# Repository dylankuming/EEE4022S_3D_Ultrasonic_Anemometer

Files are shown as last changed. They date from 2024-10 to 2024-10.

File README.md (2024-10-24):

# EEE4022S 3D Ultrasonic Anemometer

This repository contains the complete development files for the **3D Ultrasonic Anemometer** project developed as part of the EEE4022S course. The goal of the project is to design, build, and test a low-cost, accurate, and reliable 3D ultrasonic anemometer using Commercial-Off-The-Shelf (COTS) components. The system measures wind data in three dimensions (X, Y, and Z) using ultrasonic transducers and provides real-time data visualisation.

## Repository Structure

This repository is organized into three main directories:

1. **Arduino_code**: Contains all the Arduino code required to interface with the ultrasonic transducers, perform wind speed and direction calculations, and handle the data acquisition process.
   - [More details can be found in the `Arduino_code/README.md`](https://github.com/dylankuming/EEE4022S_3D_Ultrasonic_Anemometer/blob/main/Arduino_code/README.md)

2. **KiCad_folders**: Includes the KiCad schematics and PCB design files for the digital and analog circuits used in the project. These files outline the hardware design and connections between components. The following KiCad folders are included:

   - **Analog Board**: Contains the PCB design for the analog circuit.
     - [More details can be found in the `Analog Board README.md`](https://github.com/dylankuming/EEE4022S_3D_Ultrasonic_Anemometer/blob/main/KiCad_folders/analog_board/README.md)

   - **2D Digital Board**: Contains the PCB design for the 2D digital circuit.
     - [More details can be found in the `2D Digital Board README.md`](https://github.com/dylankuming/EEE4022S_3D_Ultrasonic_Anemometer/tree/main/KiCad_folders/2d_digital_board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)

   - **3D Digital Board**: Contains the PCB design for the 3D digital circuit.
     - [More details can be found in the `3D Digital Board README.md`](https://github.com/dylankuming/EEE4022S_3D_Ultrasonic_Anemometer/blob/main/KiCad_folders/3d_digital_board/README.md)

3. **matlab_code**: This directory contains MATLAB scripts used for data visualization and further analysis of the anemometer's outputs. The scripts allow for the real-time display of wind speed and direction data.
   - [More details can be found in the `matlab_code/README.md`](https://github.com/dylankuming/EEE4022S_3D_Ultrasonic_Anemometer/blob/main/matlab_code/README.md)

## Getting Started

### Prerequisites

- Arduino IDE for uploading and running the Arduino code.
- KiCad for viewing and editing the PCB design files.
- MATLAB for running the data visualization scripts.

### Installation and Usage

1. **Arduino Code**: Navigate to the `Arduino_code` folder, open the relevant `.ino` file in the Arduino IDE, and upload it to your Arduino board.
2. **KiCad Files**: Open the KiCad project files in the `KiCad_folders` directory to explore or modify the circuit designs.
3. **MATLAB Scripts**: Run the MATLAB scripts from the `matlab_code` folder to visualize the wind data captured by the anemometer.

## License

This project is open-source, and all contributions are welcome. You are free to modify and distribute the code under the terms of the MIT license.

## Author

- **Dylan Kuming**
  - Date: October, 2024

## Acknowledgements

This project was supervised by **Dr. Stephen Paine** and completed as part of the EEE4022S course at the **University of Cape Town**.

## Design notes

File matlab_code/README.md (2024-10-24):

# MATLAB Wind Visualisation for 3D Ultrasonic Anemometer

This MATLAB script connects to an Arduino via serial communication and streams wind speed data from the **3D Ultrasonic Anemometer** in three axes: North-South (NS), East-West (EW), and Top-Bottom (TB). The script processes this data and visualizes it in real time using multiple plot types, including 3D quiver plots, line graphs, and polar plots.

## Features

- **3D Quiver Plot with Trailing Vectors**: Shows the wind direction and magnitude in real time in a 3D space, along with trailing lines for visual tracking.
- **Smoothed Line Graph**: Displays the wind speed over time for all three axes (NS, EW, TB).
- **Polar Plot**: Illustrates the resultant wind direction and speed on a polar graph.
- **Digital Readout**: Provides real-time information on the resultant wind speed, direction (in both degrees and cardinal direction), and elevation angle.
  
## How to Use

### 1. Connect the Arduino

- Make sure the Arduino, loaded with [`3D_Ultrasonic_Anemometer.ino`](https://github.com/dylankuming/EEE4022S_3D_Ultrasonic_Anemometer/blob/main/Arduino_code/3D_Ultrasonic_Anemometer.ino), is connected to your computer and is streaming wind data via a serial connection.
- Replace `"COM3"` in the script with the correct port for your Arduino (you can find the correct port in the Arduino IDE).

```matlab
s = serialport("COM3", 9600); % Change "COM3" to your Arduino's COM port
```

### 2. Run the Script

- Open the [3D_Matlab_visual_output.m](https://github.com/dylankuming/EEE4022S_3D_Ultrasonic_Anemometer/blob/main/matlab_code/3D_Matlab_visual_output.m) script in MATLAB.
- Run the script by pressing the **Run** button or by typing `run` in the MATLAB command window.

### 3. Visualisation

- The script collects 1000 data points from the Arduino and updates the following visualisations in real time:
  - **3D Quiver Plot**: A 3D vector plot that shows wind direction and magnitude in space, with a trailing line for visual history.
  - **Line Graph**: A real-time plot of wind speed over time for each axis (NS, EW, TB).
  - **Polar Plot**: Displays the resultant wind direction and speed on a polar coordinate plot.
  - **Digital Readout**: Displays current wind speed, direction (in degrees and cardinal direction), and elevation angle.

### 4. Data Collection and Visualisation

- The script collects data for 1000 iterations, where each data point contains the wind speed along the NS, EW, and TB axes. 
- It calculates:
  - **Resultant Wind Speed**: The overall wind speed from the three components.
  - **Wind Direction**: The direction of the wind in degrees.
  - **Cardinal Direction**: The wind direction in cardinal terms (e.g., North, East, South, etc.).
  - **Elevation Angle**: The vertical component of the wind based on the TB axis.
  
### Sample Data Format (from Arduino):
```plaintext
NS:<value>,EW:<value>,TB:<value>
```

### Example Output
- Wind speed: `8.65 m/s`
- Wind direction: `45.0° (North-East)`
- Elevation angle: `12.5°`

## Visualisation Details

- **3D Quiver Plot**: Visualizes wind vectors in a 3D space, showing the real-time wind direction and magnitude. The plot is updated dynamically as new data is received from the Arduino.
- **Smoothed Line Graph**: Shows the wind speed variation over time for each axis (NS, EW, TB). The plot is continuously updated as data is received.
- **Polar Plot**: Displays the resultant wind direction and speed on a polar graph, helping users visualize where the wind is coming from.
- **Digital Readout**: Provides real-time numerical values for resultant wind speed, direction, and elevation.

## License

This MATLAB script is open-source and available for modification and distribution. Feel free to use and improve upon the code.

## Author

- **Dylan Kuming**
  - Date: October, 2024

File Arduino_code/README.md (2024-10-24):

# 3D Ultrasonic Anemometer Arduino Code

This project implements a **3D ultrasonic anemometer** for measuring wind data across three axes: North-South (NS), East-West (EW), and Top-Bottom (TB). The system uses ultrasonic transducers and calculates wind speed by measuring the time-of-flight (ToF) of sound pulses between the transducers.

The original 2D version of the code was written by **Lukas Fässler** and has been modified for 3D wind measurements by **Dylan Kuming**.

## Overview

The **3D Ultrasonic Anemometer** measures wind speed in all three dimensions using ultrasonic transducers. The time difference in sound pulses between pairs of transducers provides the wind speed, while the direction and elevation angle are computed based on phase and vertical components.

### Key Features:
- **3D Wind Measurement**: Accurate wind measurement in NS, EW, and TB axes.
- **Temperature Sensor**: Used for temperature compensation as it affects the speed of sound.
- **LCD Display**: Provides a real-time display of measurements.
- **Arduino Controlled**: The system is managed using an Arduino microcontroller.

### Components:
- **Ultrasonic Transducers**: Measure wind speed through sound waves.
- **Temperature Sensor**: Reads ambient temperature to account for speed of sound variation.
- **LCD Display**: Shows real-time measurements such as wind speed, phase, and elevation. Alternatively, for visual output, you can use the [MATLAB script](https://github.com/dylankuming/EEE4022S_3D_Ultrasonic_Anemometer/blob/main/matlab_code/3D_Matlab_visual_output.m) to generate a graphical representation.
- **Arduino**: Controls the ultrasonic pulses and processes the wind data.

### Project Structure:
- [`3D_Ultrasonic_Anemometer.ino`](https://github.com/dylankuming/EEE4022S_3D_Ultrasonic_Anemometer/blob/main/Arduino_code/3D_Ultrasonic_Anemometer.ino): Contains the Arduino code that handles the measurement process.

## How It Works

1. **Sound Pulse Emission**: The Arduino controls the ultrasonic transducers to emit sound pulses along the three axes.
2. **Time-of-Flight (ToF) Calculation**: The time taken for the pulse to travel between transducers is measured.
3. **Wind Speed and Direction**: Wind speed is calculated from the difference in ToF along opposite directions (e.g., NS vs SN). The direction is determined using trigonometry.
4. **Vertical Wind Component**: The system also calculates the vertical wind speed using the top-bottom axis.

### Measurements:
- **NS Wind Speed**: Wind speed in the North-South axis.
- **EW Wind Speed**: Wind speed in the East-West axis.
- **TB Wind Speed**: Wind speed in the Top-Bottom axis.
- **Magnitude**: Overall wind speed magnitude across the three axes.
- **Phase**: Wind direction in degrees.
- **Elevation**: Vertical angle of the wind.

## Hardware Setup

The following components and connections are used in the project:

- **AXIS1 (Pin 13)**: Determines the operational plane for measurement.
- **AXIS2 (Pin 12)**: Controls the second axis (NS/EW vs TB).
- **DIRECTION (Pin 11)**: Sets the direction of the sound pulse.
- **SIGNAL (Pin 10)**: Pulse Width Modulation (PWM) signal for driving transducers.
- **MUTE (Pin 9)**: Mutes the amplifier during transmission and unmutes during reception.
- **Envelope Detector (Pin 7)**: Captures the envelope of the signal.
- **Zero-Crossing Detector (Pin 8)**: Captures the zero-crossing signal.
- **Temperature Sensor (Pin A0)**: Reads ambient temperature for compensating the speed of sound.
- **LCD Connections (Pins A1-A3, D3-D6)**: Used to control the 16x2 LCD.

### Additional Required Hardware:
- Ultrasonic transducers.
- [Analog Board](https://github.com/dylankuming/EEE4022S_3D_Ultrasonic_Anemometer/tree/main/KiCad_folders/analog_board).
- [3D Digital Board](https://github.com/dylankuming/EEE4022S_3D_Ultrasonic_Anemometer/tree/main/KiCad_folders/3d_digital_board).
- Arduino-compatible microcontroller.
- LCD 16x2 display.

## Output Data

The system outputs the following data over the serial interface:
- **NS Wind Speed**: Wind speed in the North-South direction (in m/s).
- **EW Wind Speed**: Wind speed in the East-West direction (in m/s).
- **TB Wind Speed**: Wind speed in the Top-Bottom direction (in m/s).
- **Magnitude**: The overall wind speed magnitude calculated using the three axes.
- **Phase**: Wind direction based on NS and EW components.
- **Elevation**: Wind elevation based on the TB axis.

The LCD displays the same data in real-time, providing an easy interface for monitoring wind conditions.

## License

This project is open-source, and all contributions are welcome. You are free to modify and distribute the code under the terms of the MIT license.

## Author

- **Dylan Kuming**
  - Date: October, 2024

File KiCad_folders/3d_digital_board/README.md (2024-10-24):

# 3D Digital Board for 3D Ultrasonic Anemometer

This folder contains the KiCad design files for the **3D Digital Board** used in the 3D Ultrasonic Anemometer. This board expands on the 2D version by adding control for the Top-Bottom (TB) axis, allowing for full 3D wind measurement. It manages the ultrasonic transducers in the NS, EW, and TB directions and processes signals for calculating wind speed and direction in three dimensions.

## Features
- **3D Wind Measurement**: Adds the third axis (Top-Bottom) to enable full 3D wind speed and direction measurement.
- **Expanded Multiplexing**: Uses additional multiplexers to handle signals from six transducers.
- **Transducer Control**: Selects and drives the appropriate transducers for the NS, EW, and TB axes.

## Key Components
- **74HC138 3-to-8 Line Decoder**: Controls the selection of transducer pairs for the three-dimensional setup.
- **74HC4051 Multiplexer**: Routes the received signals from all six transducers to the analog board for processing.
- **Hex Inverters**: Controls the ultrasonic transducers.

## Files in this Folder
- [3D_Digital_Board_Schematic.sch](https://github.com/dylankuming/EEE4022S_3D_Ultrasonic_Anemometer/blob/main/KiCad_folders/3d_digital_board/3D_Digital.kicad_sch): The KiCad schematic of the 3D digital board.
- [3D_Digital_Board_PCB.kicad_pcb](https://github.com/dylankuming/EEE4022S_3D_Ultrasonic_Anemometer/blob/main/KiCad_folders/3d_digital_board/3D_Digital.kicad_pcb): The PCB layout for the 3D digital board.

## Usage
1. **Open the Schematic**: Use KiCad to open and modify the schematic for the 3D digital board.
2. **Edit PCB Layout**: Review the PCB layout to make any necessary adjustments.
3. **Generate Gerber Files**: Export Gerber files from KiCad for PCB fabrication.

## License
This project is open-source under the MIT License.

## Author

- **Dylan Kuming**
  - Date: October, 2024

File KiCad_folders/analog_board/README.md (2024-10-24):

# Analog Board for 3D Ultrasonic Anemometer

This folder contains the KiCad design files for the **Analog Board** used in the 3D Ultrasonic Anemometer. The Analog Board plays a crucial role in processing the ultrasonic signals received from the transducers. It is responsible for signal amplification, envelope detection, and zero-crossing detection, which are required to measure the time-of-flight (ToF) of the ultrasonic pulses.

## Features
- **Signal Amplification**: Boosts the received ultrasonic signals to detectable levels.
- **Envelope Detection**: Extracts the amplitude variations of the signals for timing analysis.
- **Zero-Crossing Detection**: Detects the zero-crossing points of the ultrasonic waves for more precise ToF measurement.
- **Temperature Compensation**: Includes a temperature sensor for compensating the speed of sound based on environmental temperature.

## Components
- Tuned amplifiers for signal conditioning.
- Envelope detectors to capture signal peaks.
- Zero-crossing detectors to mark the precise timing of signal transitions.
- Temperature sensor for environmental adjustments.

## Files in this Folder
- [Analog_Board_Schematic.sch](https://github.com/dylankuming/EEE4022S_3D_Ultrasonic_Anemometer/blob/main/KiCad_folders/analog_board/Analog.kicad_sch): The KiCad schematic of the analog board.
- [Analog_Board_PCB.kicad_pcb](https://github.com/dylankuming/EEE4022S_3D_Ultrasonic_Anemometer/blob/main/KiCad_folders/analog_board/Analog.kicad_pcb): The PCB layout for the analog board.

## Usage
1. **Open the Schematic**: Load the schematic file into KiCad to view the circuit.
2. **View or Edit the PCB**: Open the PCB layout file to review the placement and routing of components.
3. **Generate Fabrication Files**: Export the necessary Gerber files from KiCad for PCB fabrication.

## License
This project is open-source under the MIT License.

## Author

- **Dylan Kuming**
  - Date: October, 2024

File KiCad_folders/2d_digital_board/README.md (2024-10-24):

# 2D Digital Board for 2D Ultrasonic Anemometer

This folder contains the KiCad design files for the **2D Digital Board** used in the 2D version of the Ultrasonic Anemometer. This board is designed to control and manage the transducers along two axes: North-South (NS) and East-West (EW). It sends and receives ultrasonic pulses and calculates wind speed and direction in two dimensions.

## Features
- **Transducer Control**: Manages the transducers for both the NS and EW axes.
- **Multiplexing**: Uses multiplexers to route the signals to and from the appropriate transducers.

## Key Components
- **74HC139 Decoder**: Controls the transducer selection for NS and EW.
- **74HC368 Hex Inverters**: Drives the ultrasonic transducers.
- **74HC4052 Multiplexers**: Routes the signals to the analog board for processing.

## Files in this Folder
- [2D_Digital_Board_Schematic.sch](https://github.com/dylankuming/EEE4022S_3D_Ultrasonic_Anemometer/blob/main/KiCad_folders/2d_digital_board/Digital.kicad_sch): The KiCad schematic of the 2D digital board.
- [2D_Digital_Board_PCB.kicad_pcb](https://github.com/dylankuming/EEE4022S_3D_Ultrasonic_Anemometer/blob/main/KiCad_folders/2d_digital_board/Digital.kicad_pcb): The PCB layout for the 2D digital board.

## Usage
1. **Open the Schematic**: Load the schematic file into KiCad to view or modify the design.
2. **View or Edit the PCB**: Review the PCB layout and adjust the component placement as needed.
3. **Fabrication**: Generate Gerber files from KiCad for PCB manufacturing.

## License
This project is open-source under the MIT License.

## Author

- **Dylan Kuming**
  - Date: October, 2024

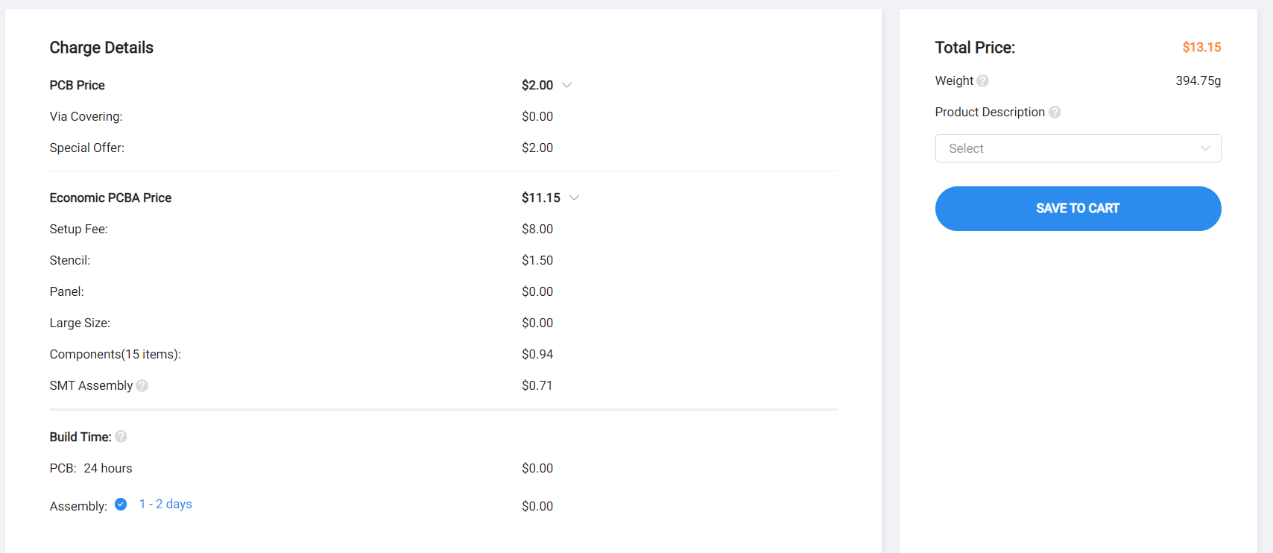
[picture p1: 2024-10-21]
KiCad_folders/analog_board/Screenshot 2024-08-29 081555.png

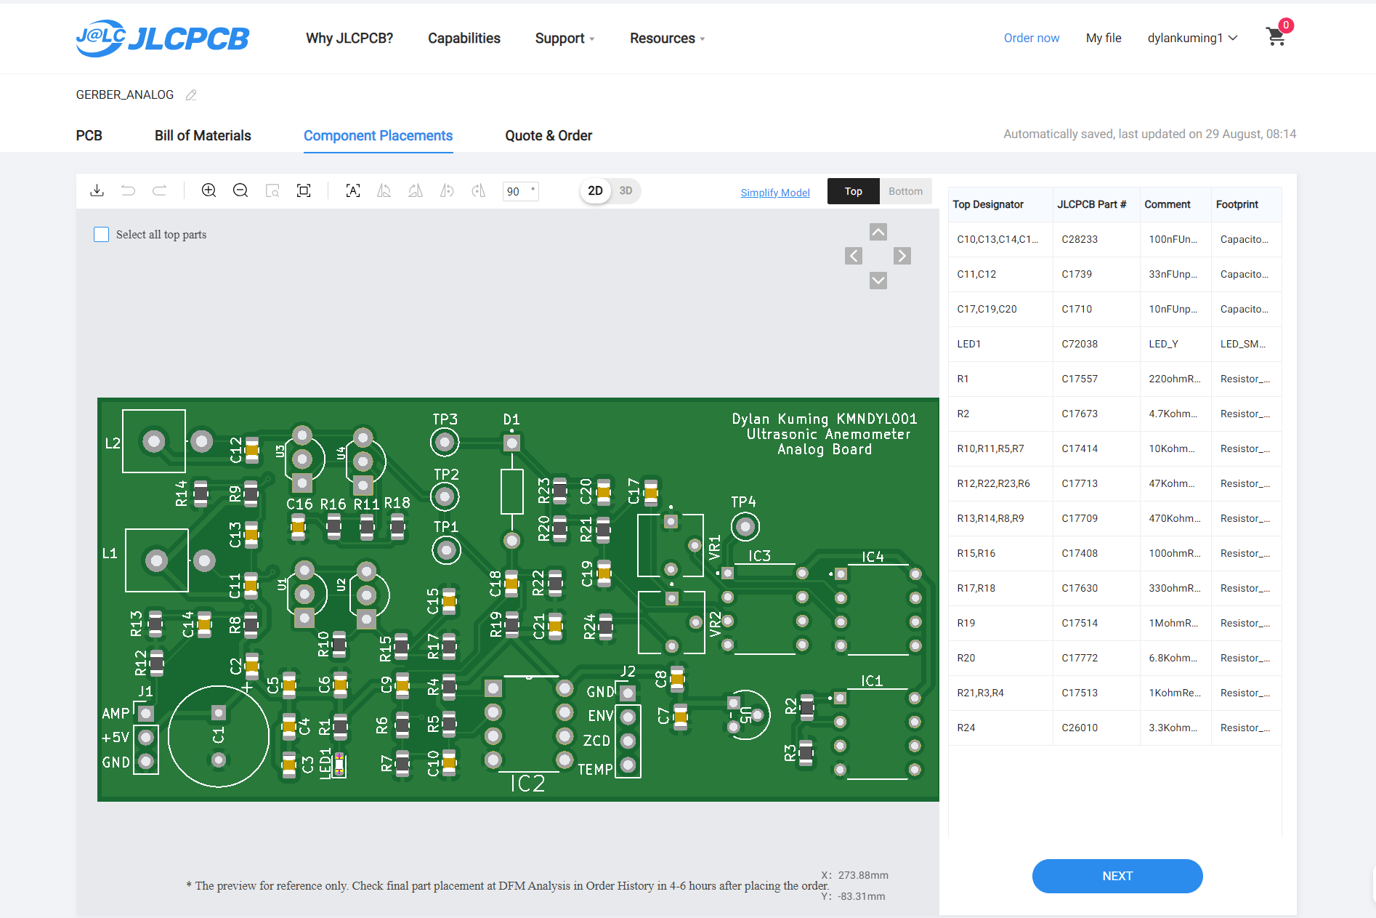
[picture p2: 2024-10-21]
KiCad_folders/analog_board/Screenshot 2024-08-29 081522.png

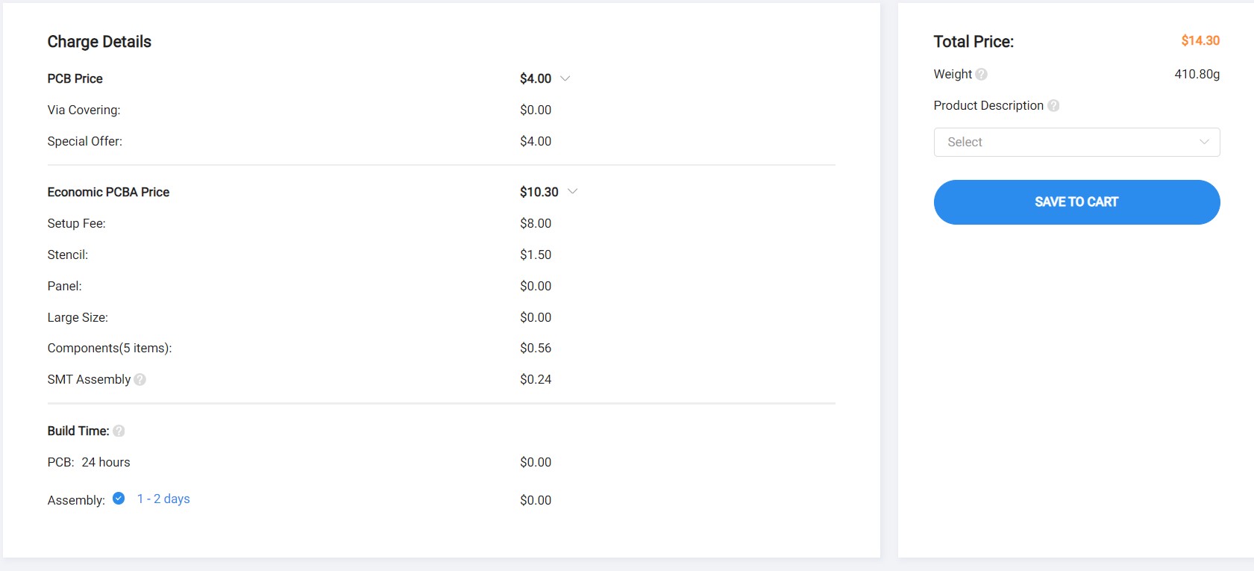
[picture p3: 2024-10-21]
KiCad_folders/3d_digital_board/Quote.jpg

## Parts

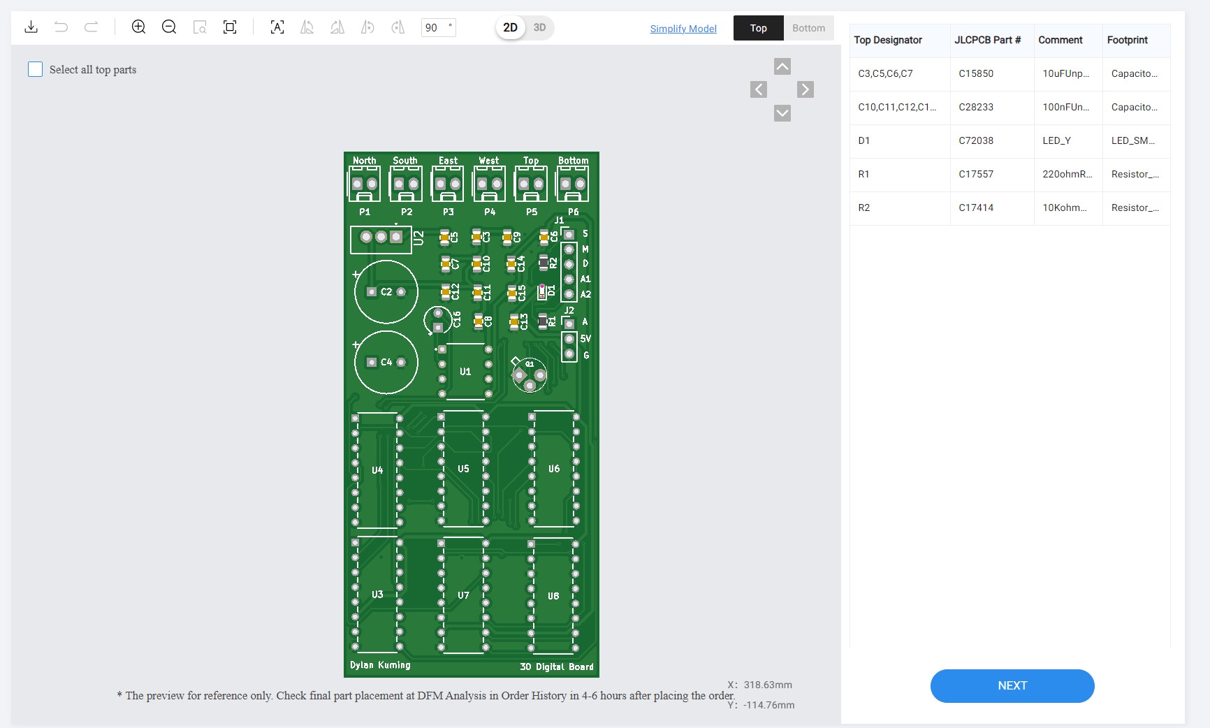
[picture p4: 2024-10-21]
KiCad_folders/3d_digital_board/Component placement.jpg

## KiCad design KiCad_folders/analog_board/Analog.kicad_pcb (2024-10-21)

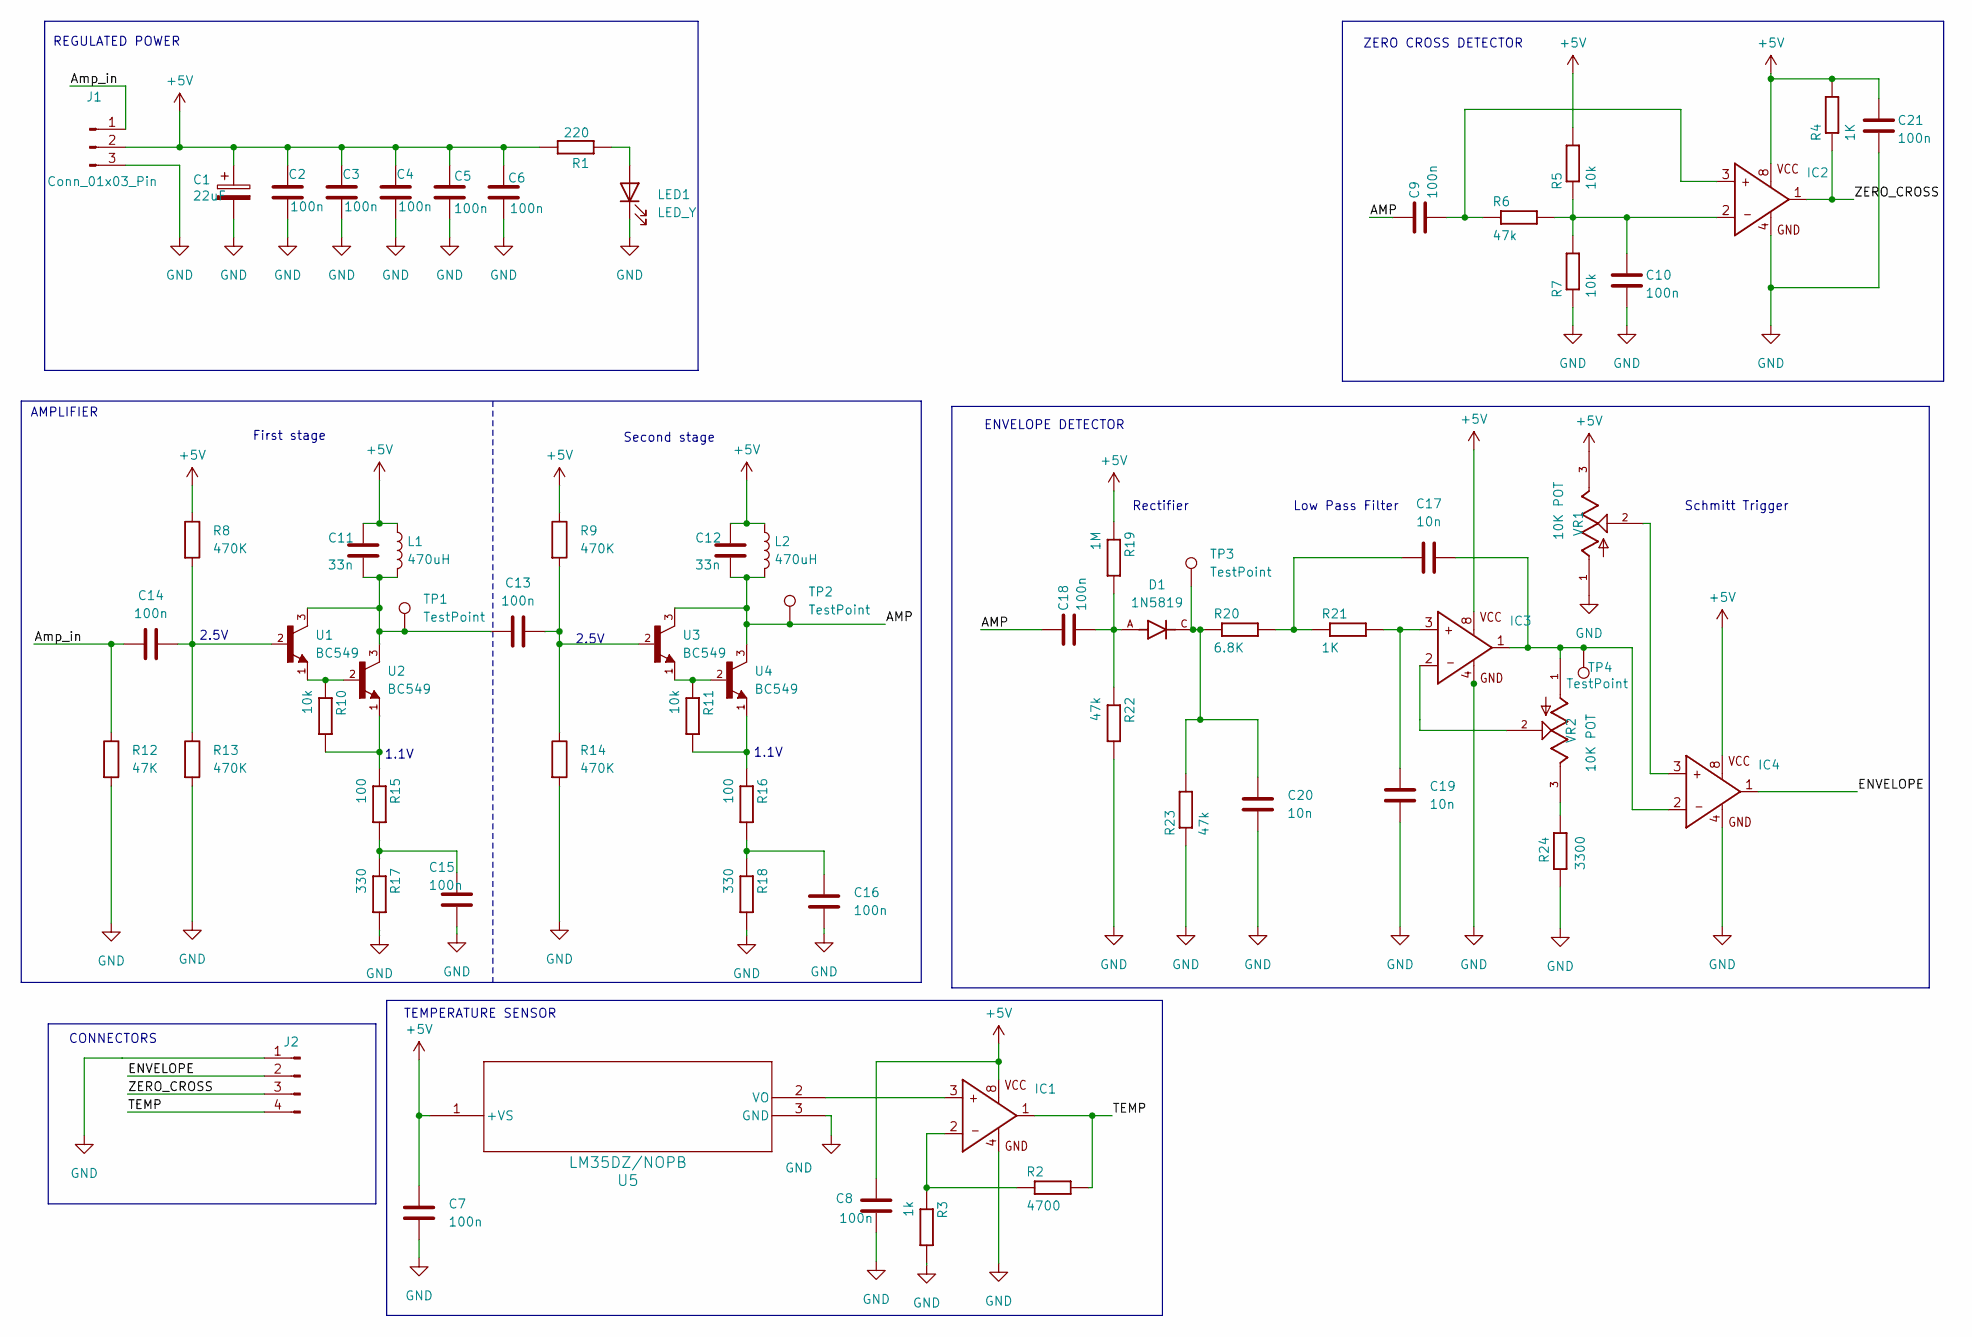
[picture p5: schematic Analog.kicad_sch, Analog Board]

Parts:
C1: 22uF; CP_Radial_Tantal_D10.5mm_P5.00mm
C2, C3, C4, C5, C6, C7, C8, C9, C10, C13, C14, C15, C16, C18, C21: 100n; C_0805_2012Metric
C11, C12: 33n; C_0805_2012Metric
C17, C19, C20: 10n; C_0805_2012Metric
D1: 1N5819; DIOAD1036W78L470D235; PARTREV P2104
IC1, IC3, IC4: LM358; DIP794W45P254L959H508Q8
IC2: LM393; DIP254P762X508-8
J1: Conn_01x03_Pin; PinHeader_1x03_P2.54mm_Vertical
J2: Conn_01x04_Pin; PinHeader_1x04_P2.54mm_Vertical
L1, L2: 470uH; R_Axial_Power_L20.0mm_W6.4mm_P5.08mm_Vertical
LED1: LED_Y; LED_0603_1608Metric
R1: 220; R_0805_2012Metric
R2: 4700; R_0805_2012Metric
R3: 1k; R_0805_2012Metric
R4, R21: 1K; R_0805_2012Metric
R5, R7, R10, R11: 10k; R_0805_2012Metric
R6, R22, R23: 47k; R_0805_2012Metric
R8, R9, R13, R14: 470K; R_0805_2012Metric
R12: 47K; R_0805_2012Metric
R15, R16: 100; R_0805_2012Metric
R17, R18: 330; R_0805_2012Metric
R19: 1M; R_0805_2012Metric
R20: 6.8K; R_0805_2012Metric
R24: 3300; R_0805_2012Metric
TP1, TP2, TP3, TP4: TestPoint; TestPoint_Loop_D2.50mm_Drill1.0mm
U1, U2, U3, U4: BC549; TO92
U5: LM35DZ/NOPB; Z03A
VR1, VR2: 10K POT; TRIM_3362P-1-503LF; PARTREV 08/26/10

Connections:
+5V: C1.1, C2.1, C3.1, C4.1, C5.1, C6.1, C7.1, C8.1, C11.1, C12.1, C21.1, IC1.8 (VCC), IC2.8 (VCC), IC3.8 (VCC), IC4.8 (VCC), J1.2, L1.1, L2.1, R1.2, R4.2, R5.2, R8.1, R9.1, R19.1, U5.1 (+VS), VR1.3
/AMP: C9.1, C12.2, C18.1, L2.2, TP2.1, U3.3, U4.3
/Amp_in: C14.1, J1.1, R12.1
/ENVELOPE: IC4.1 (VOUT), J2.2
/TEMP: IC1.1 (VOUT), J2.4, R2.2
/ZERO_CROSS: IC2.1 (VOUT), J2.3, R4.1
GND: C1.2, C2.2, C3.2, C4.2, C5.2, C6.2, C7.2, C8.2, C10.2, C15.2, C16.2, C19.2, C20.2, C21.2, IC1.4 (GND), IC2.4 (GND), IC3.4 (GND), IC4.4 (GND), J1.3, J2.1, LED1.1 (K), R3.2, R7.1, R12.2, R13.2, R14.2, R17.2, R18.2, R22.2, R23.1, R24.1, U5.3 (GND), VR1.1
unnamed: C11.2, C13.1, L1.2, TP1.1, U1.3, U2.3
unnamed: C13.2, R9.2, R14.1, U3.2
unnamed: C14.2, R8.2, R13.1, U1.2
unnamed: C15.1, R15.2, R17.1
unnamed: C16.1, R16.2, R18.1
unnamed: C17.1, R20.2, R21.1
unnamed: C18.2, D1.A, R19.2, R22.1
unnamed: C20.1, D1.C, R20.1, R23.2, TP3.1
unnamed: IC1.3 (VIN+), U5.2 (VO)
unnamed: IC1.2 (VIN-), R2.1, R3.1
unnamed: C9.2, IC2.3 (VIN+), R6.1
unnamed: C10.1, IC2.2 (VIN-), R5.1, R6.2, R7.2
unnamed: C19.1, IC3.3 (VIN+), R21.2
unnamed: IC3.2 (VIN-), VR2.2
unnamed: C17.2, IC3.1 (VOUT), IC4.2 (VIN-), TP4.1, VR2.1
unnamed: IC4.3 (VIN+), VR1.2
unnamed: LED1.2 (A), R1.1
unnamed: R10.1, U1.1, U2.2
unnamed: R10.2, R15.1, U2.1
unnamed: R11.1, U3.1, U4.2
unnamed: R11.2, R16.1, U4.1
unnamed: R24.2, VR2.3

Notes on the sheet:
Second stage
REGULATED POWER
ZERO CROSS DETECTOR
Low Pass Filter
First stage
TEMPERATURE SENSOR
Rectifier
1.1V
Schmitt Trigger
2.5V
CONNECTORS
AMPLIFIER
ENVELOPE DETECTOR

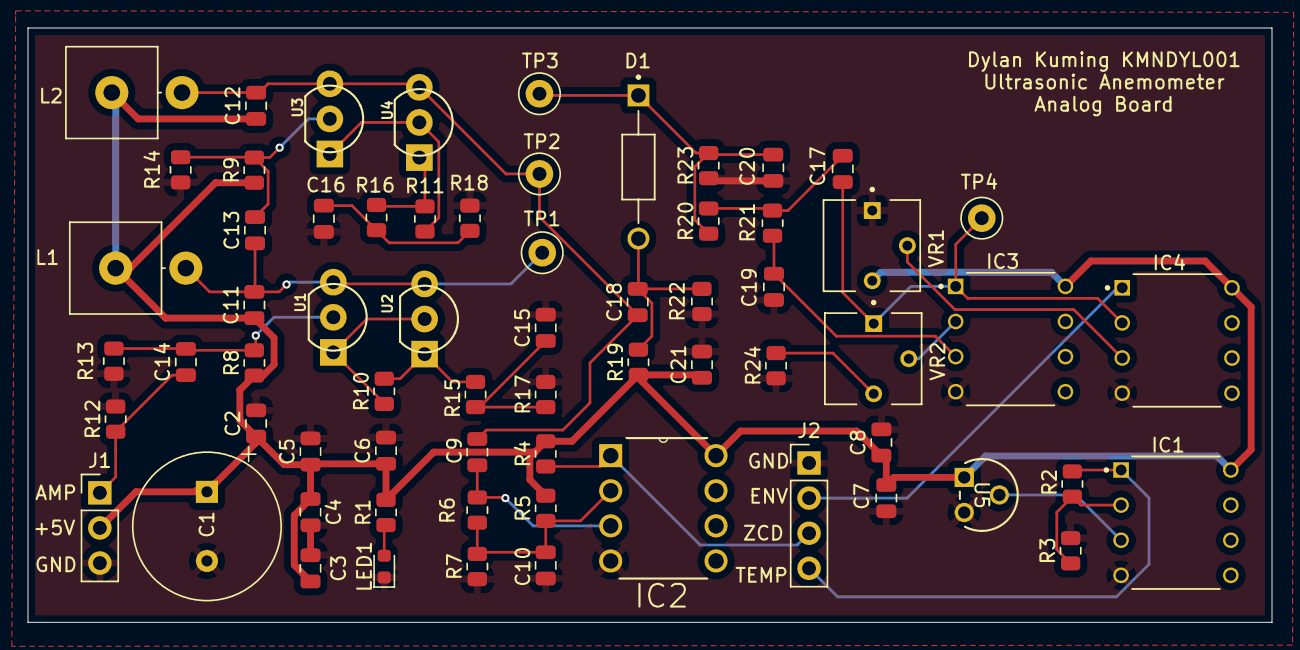
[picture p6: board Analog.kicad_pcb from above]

Board: 2 copper layers, 90.0 x 43.0 mm, 66 parts (0 on the bottom side), 29 nets.

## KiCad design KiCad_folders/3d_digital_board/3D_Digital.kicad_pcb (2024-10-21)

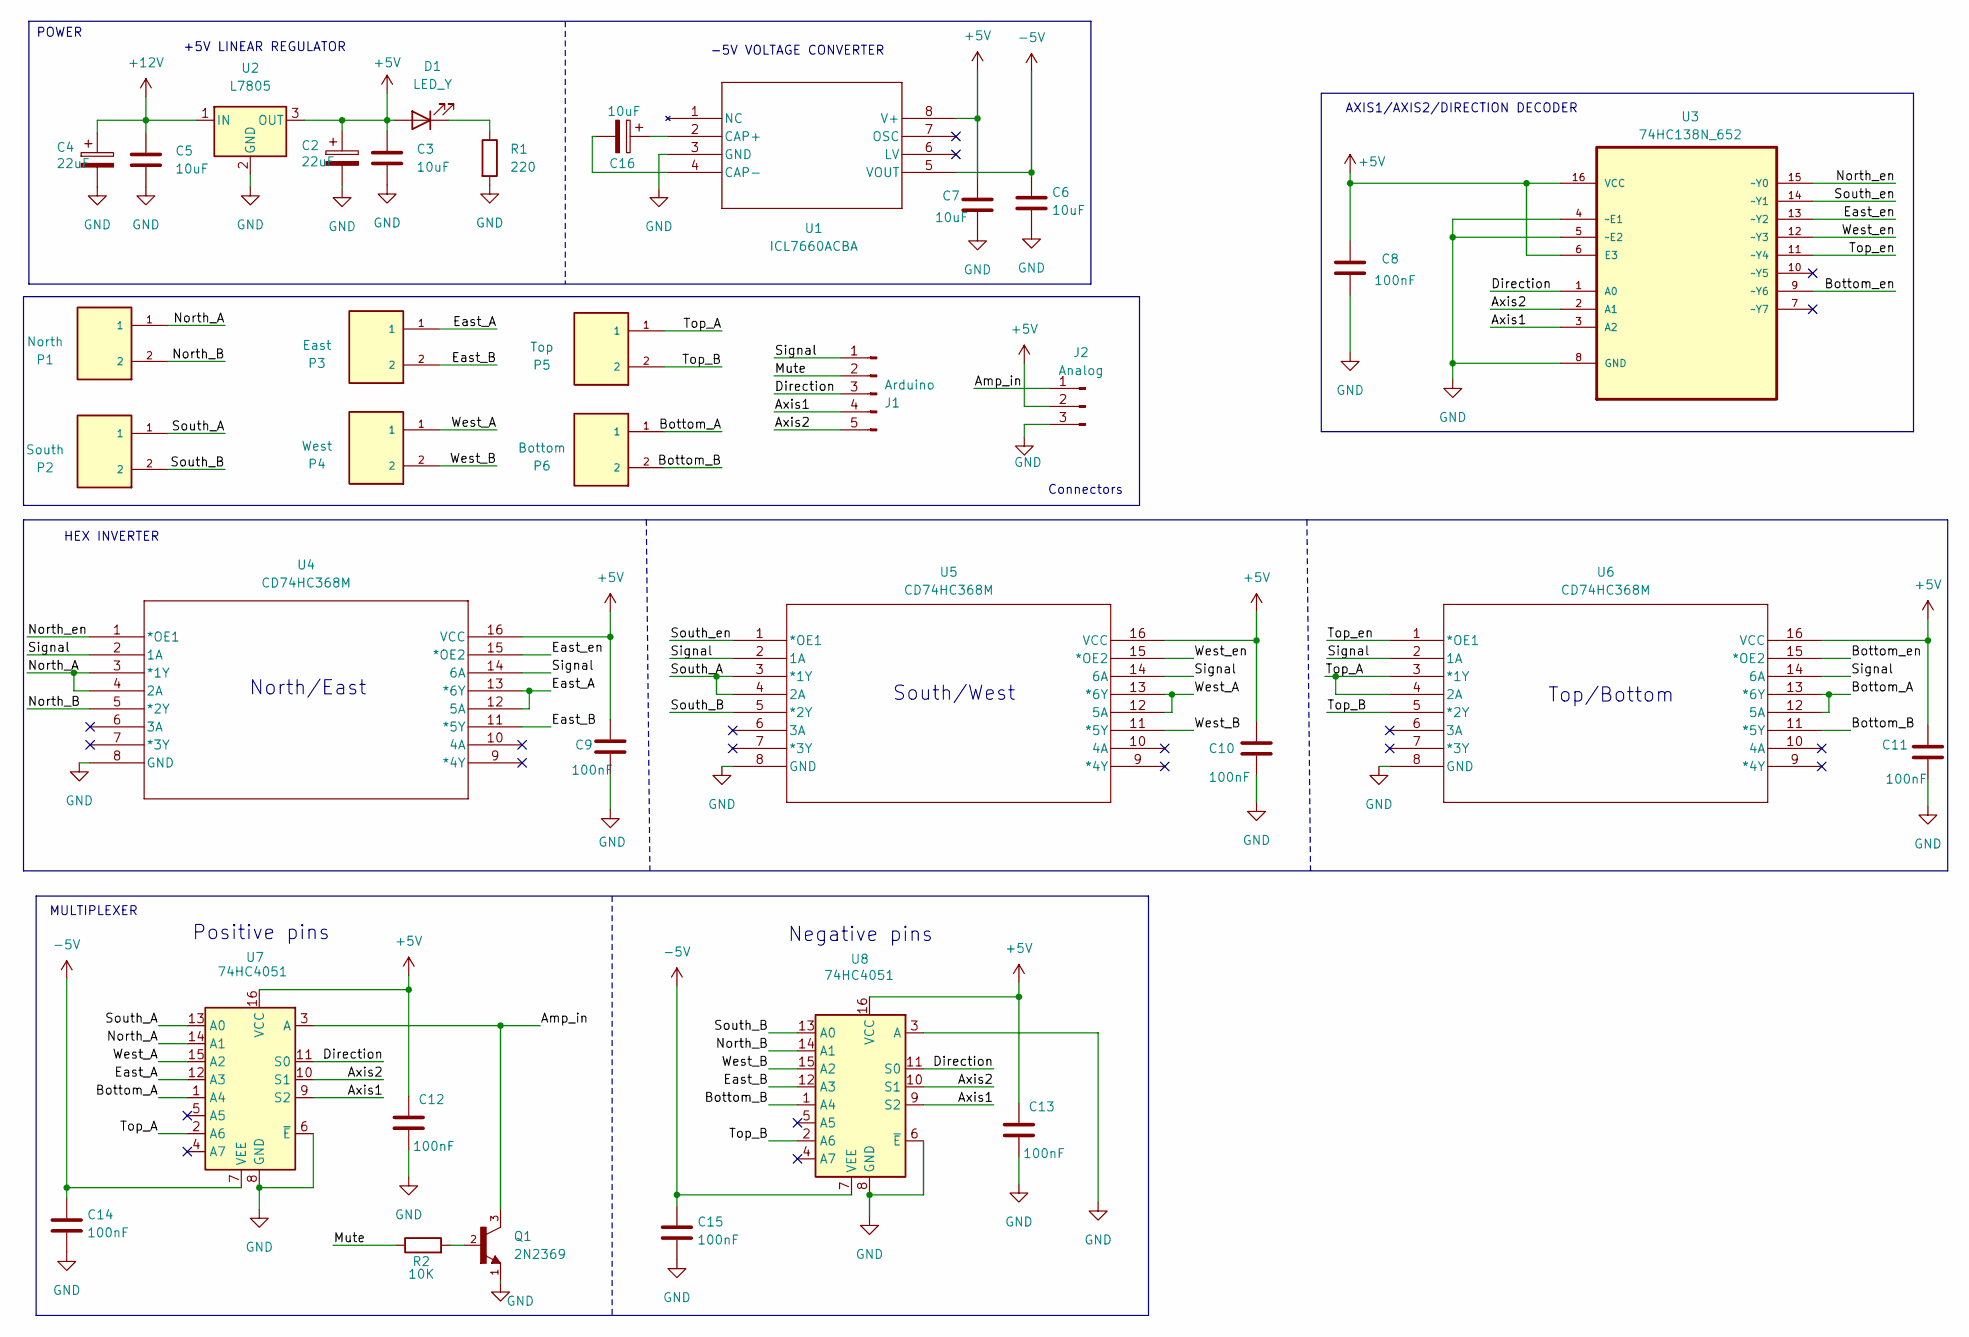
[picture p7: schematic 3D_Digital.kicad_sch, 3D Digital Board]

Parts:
C2, C4: 22uF; CP_Radial_Tantal_D10.5mm_P5.00mm
C3, C5, C6, C7: 10uF; C_0805_2012Metric
C8, C9, C10, C11, C12, C13, C14, C15: 100nF; C_0805_2012Metric
C16: 10uF; CP_Radial_Tantal_D4.5mm_P2.50mm
D1: LED_Y; LED_0603_1608Metric
J1: Arduino; PinHeader_1x05_P2.54mm_Vertical
J2: Analog; PinHeader_1x03_P2.54mm_Vertical
P1: North; Molex_KK-254_AE-6410-02A_1x02_P2.54mm_Vertical
P2: South; Molex_KK-254_AE-6410-02A_1x02_P2.54mm_Vertical
P3: East; Molex_KK-254_AE-6410-02A_1x02_P2.54mm_Vertical
P4: West; Molex_KK-254_AE-6410-02A_1x02_P2.54mm_Vertical
P5: Top; Molex_KK-254_AE-6410-02A_1x02_P2.54mm_Vertical
P6: Bottom; Molex_KK-254_AE-6410-02A_1x02_P2.54mm_Vertical
Q1: 2N2369; TO18
R1: 220; R_0805_2012Metric
R2: 10K; R_0805_2012Metric
U1: ICL7660ACBA; DIP794W45P254L959H508Q8
U2: L7805; TO255P1040X460X1968-3
U3: 74HC138N_652; SOT38-4_NXP; MPN 74HC138N,652
U4, U5, U6: CD74HC368M; SOT38-4_NXP
U7, U8: 74HC4051; SOT38-4_NXP

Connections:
+5V: C2.1, C3.1, C7.1, C8.1, C9.1, C10.1, C11.1, C12.1, C13.1, D1.2 (A), J2.2, U1.8 (V+), U2.3 (OUT), U3.6 (E3), U3.16 (VCC), U4.16 (VCC), U5.16 (VCC), U6.16 (VCC), U7.16 (VCC), U8.16 (VCC)
+12V: C4.1, C5.1, U2.1 (IN)
-5V: C6.1, C14.1, C15.1, U1.5 (VOUT), U7.7 (VEE), U8.7 (VEE)
/Amp_in: J2.1, Q1.3, U7.3 (A)
/Amp_off: J1.2, R2.1
/Axis1: J1.4, U3.3 (A2), U7.9 (S2), U8.9 (S2)
/Axis2: J1.5, U3.2 (A1), U7.10 (S1), U8.10 (S1)
/Bottom_A: P6.1, U6.12 (5A), U6.13 (*6Y), U7.1 (A4)
/Bottom_B: P6.2, U6.11 (*5Y), U8.1 (A4)
/Bottom_en: U3.9 (~Y6), U6.15 (*OE2)
/Direction: J1.3, U3.1 (A0), U7.11 (S0), U8.11 (S0)
/East_A: P3.1, U4.12 (5A), U4.13 (*6Y), U7.12 (A3)
/East_B: P3.2, U4.11 (*5Y), U8.12 (A3)
/East_en: U3.13 (~Y2), U4.15 (*OE2)
/North_A: P1.1, U4.3 (*1Y), U4.4 (2A), U7.14 (A1)
/North_B: P1.2, U4.5 (*2Y), U8.14 (A1)
/North_en: U3.15 (~Y0), U4.1 (*OE1)
/Signal: J1.1, U4.2 (1A), U4.14 (6A), U5.2 (1A), U5.14 (6A), U6.2 (1A), U6.14 (6A)
/South_A: P2.1, U5.3 (*1Y), U5.4 (2A), U7.13 (A0)
/South_B: P2.2, U5.5 (*2Y), U8.13 (A0)
/South_en: U3.14 (~Y1), U5.1 (*OE1)
/Top_A: P5.1, U6.3 (*1Y), U6.4 (2A), U7.2 (A6)
/Top_B: P5.2, U6.5 (*2Y), U8.2 (A6)
/Top_en: U3.11 (~Y4), U6.1 (*OE1)
/West_A: P4.1, U5.12 (5A), U5.13 (*6Y), U7.15 (A2)
/West_B: P4.2, U5.11 (*5Y), U8.15 (A2)
/West_en: U3.12 (~Y3), U5.15 (*OE2)
GND: C2.2, C3.2, C4.2, C5.2, C6.2, C7.2, C8.2, C9.2, C10.2, C11.2, C12.2, C13.2, C14.2, C15.2, J2.3, Q1.1, R1.2, U1.3 (GND), U2.2 (GND), U3.4 (~E1), U3.5 (~E2), U3.8 (GND), U4.8 (GND), U5.8 (GND), U6.8 (GND), U7.6 (~E), U7.8 (GND), U8.3 (A), U8.6 (~E), U8.8 (GND)
unnamed: D1.1 (K), R1.1
unnamed: Q1.2, R2.2
unnamed: C16.1, U1.2 (CAP+)
unnamed: C16.2, U1.4 (CAP-)

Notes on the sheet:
Negative pins
+5V LINEAR REGULATOR
Top/Bottom
Connectors
North/East
-5V VOLTAGE CONVERTER
AXIS1/AXIS2/DIRECTION DECODER
MULTIPLEXER
POWER
HEX INVERTER
Positive pins
South/West

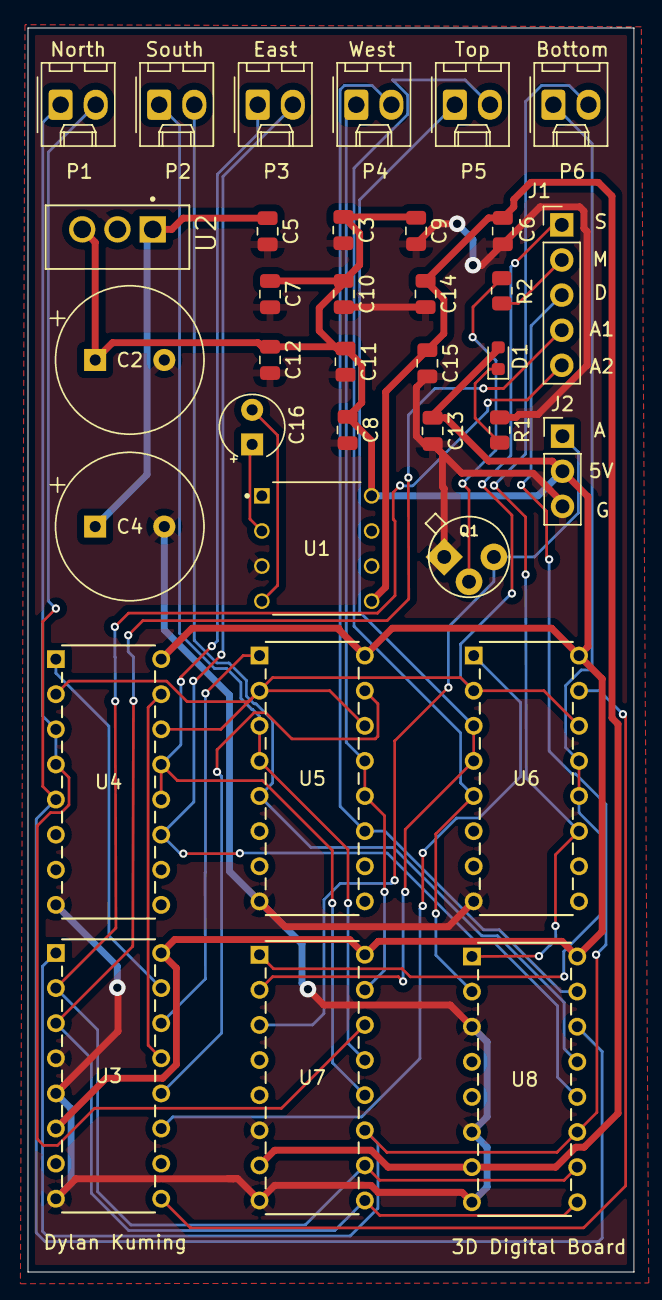
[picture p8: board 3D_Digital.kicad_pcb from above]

Board: 2 copper layers, 43.8 x 90.0 mm, 35 parts (0 on the bottom side), 32 nets.

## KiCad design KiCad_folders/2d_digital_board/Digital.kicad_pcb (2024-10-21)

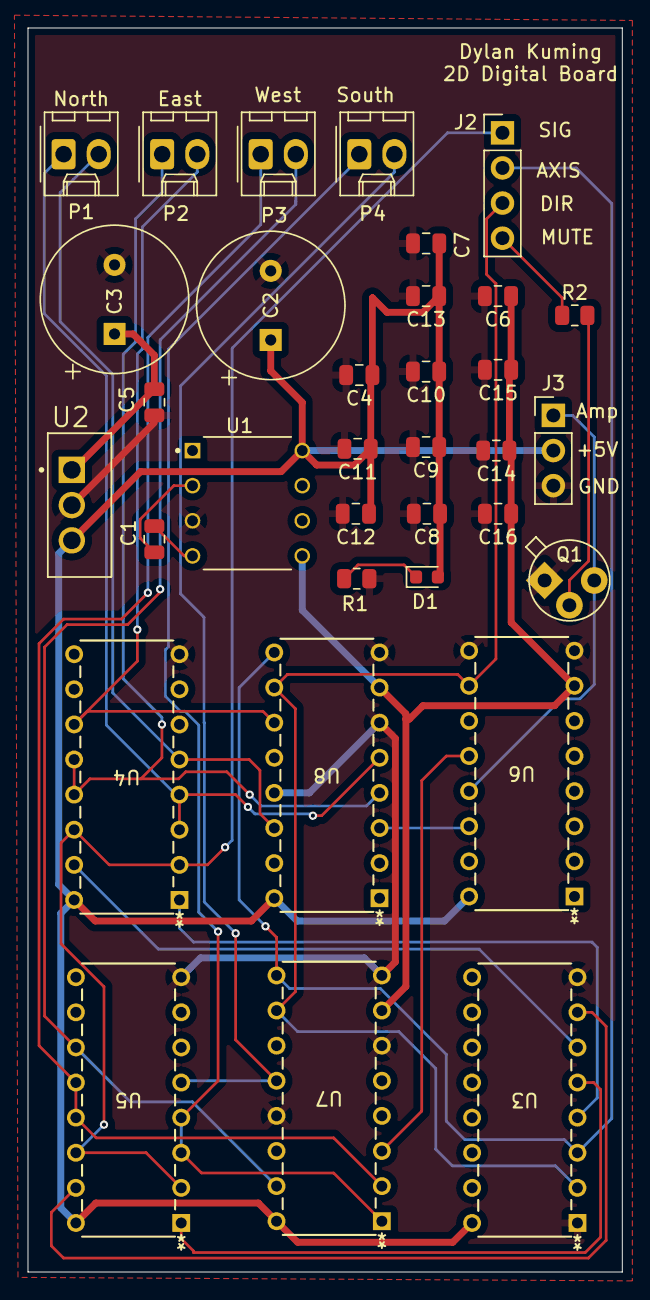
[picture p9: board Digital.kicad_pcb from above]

Board: 2 copper layers, 43.0 x 90.0 mm, 34 parts (0 on the bottom side), 27 nets.

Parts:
C1, C4, C5, C6, C7: 10uF; C_0805_2012Metric
C2, C3: 22uF; CP_Radial_Tantal_D10.5mm_P5.00mm
C8, C9, C10, C11, C12, C13, C14, C15, C16: 100nF; C_0805_2012Metric
D1: LED_Y; LED_0603_1608Metric
J2: Arduino; PinHeader_1x04_P2.54mm_Vertical
J3: Analog; PinHeader_1x03_P2.54mm_Vertical
P1: North; Molex_KK-254_AE-6410-02A_1x02_P2.54mm_Vertical
P2: East; Molex_KK-254_AE-6410-02A_1x02_P2.54mm_Vertical
P3: West; Molex_KK-254_AE-6410-02A_1x02_P2.54mm_Vertical
P4: South; Molex_KK-254_AE-6410-02A_1x02_P2.54mm_Vertical
Q1: 2N2369; TO18
R1: 220; R_0805_2012Metric
R2: 10K; R_0805_2012Metric
U1: ICL7660ACBA; DIP794W45P254L959H508Q8
U2: L7805; TO255P1040X460X1968-3
U3: MC74HC139ADG; SOT38-4_NXP
U4, U5: CD74HC368M; SOT38-4_NXP
U6, U7, U8: MC74HC4052ADG; SOT38-4_NXP

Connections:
+5V: C2.1, C4.1, C7.1, C8.1, C9.1, C10.1, C11.1, C12.1, C13.1, D1.2 (A), J3.2, U1.8 (V+), U2.3 (OUT), U3.16 (VCC), U4.16 (VCC), U5.16 (VCC), U6.16 (VCC), U7.16 (VCC), U8.16 (VCC)
+12V: C3.1, C5.1, U2.1 (IN)
-5V: C6.1, C14.1, C15.1, C16.1, U1.5 (VOUT), U6.7 (VEE), U7.7 (VEE), U8.7 (VEE)
/Amp_in: J3.1, Q1.3, U6.13 (X)
/Amp_off: J2.4, R2.1
/Axis: J2.2, U3.3 (A1A), U7.9 (B), U8.9 (B)
/Direction: J2.3, U3.2 (A0A), U6.10 (A), U7.10 (A), U8.10 (A)
/East_A: P2.1, U4.12 (5A), U4.13 (*6Y), U8.4 (Y3)
/East_B: P2.2, U4.11 (*5Y), U8.11 (X3)
/East_en: U3.6 (Y2A), U4.15 (*OE2)
/NorthEast: U6.14 (X1), U8.3 (Y)
/North_A: P1.1, U4.3 (*1Y), U4.4 (2A), U8.5 (Y1)
/North_B: P1.2, U4.5 (*2Y), U8.14 (X1)
/North_en: U3.4 (Y0A), U4.1 (*OE1)
/Signal: J2.1, U4.2 (1A), U4.14 (6A), U5.2 (1A), U5.14 (6A)
/SouthWest: U6.12 (X0), U7.3 (Y)
/South_A: P4.1, U5.3 (*1Y), U5.4 (2A), U7.1 (Y0)
/South_B: P4.2, U5.5 (*2Y), U7.12 (X0)
/South_en: U3.5 (Y1A), U5.1 (*OE1)
/West_A: P3.1, U5.12 (5A), U5.13 (*6Y), U7.2 (Y2)
/West_B: P3.2, U5.11 (*5Y), U7.15 (X2)
/West_en: U3.7 (Y3A), U5.15 (*OE2)
GND: C2.2, C3.2, C4.2, C5.2, C6.2, C7.2, C8.2, C9.2, C10.2, C11.2, C12.2, C13.2, C14.2, C15.2, C16.2, J3.3, Q1.1, R1.2, U1.3 (GND), U2.2 (GND), U3.1 (SELECTA), U3.8 (GND), U4.8 (GND), U5.8 (GND), U6.8 (GND), U6.9 (B), U7.6 (ENABLE), U7.8 (GND), U7.13 (X), U8.6 (ENABLE), U8.8 (GND), U8.13 (X)
unnamed: D1.1 (K), R1.1
unnamed: Q1.2, R2.2
unnamed: C1.2, U1.2 (CAP+)
unnamed: C1.1, U1.4 (CAP-)

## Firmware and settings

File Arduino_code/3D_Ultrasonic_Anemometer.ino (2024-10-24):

/*
 * Ultrasonic Anemometer Sketch, v0.2 (3D Version)
 * Modified for 3D version by Dylan Kuming
 * 2024-09-27
 */

#include <math.h>
#include <LiquidCrystal.h>

// Pin definitions for the LCD
#define LCD_RS A1
#define LCD_RW A2
#define LCD_EN A3
#define LCD_D7 3
#define LCD_D6 4
#define LCD_D5 5
#define LCD_D4 6

// Initialize LCD object
LiquidCrystal lcd(LCD_RS, LCD_RW, LCD_EN, LCD_D4, LCD_D5, LCD_D6, LCD_D7);

// Pin definitions for the ultrasonic system
#define AXIS1 13
#define AXIS2 12
#define DIRECTION 11
#define SIGNAL 10
#define MUTE 9
#define ZEROCROSSING 8
#define TEMPERATURE_SENSOR A0
#define TMR1_COMPB_INT A5
#define TMR1_CAPTURE_INT A4
#define CALC 2

// Direction definitions for the axes
#define NORTH_TO_SOUTH 0 /* Axis1=L, Direction=L, Axis2=L */
#define EAST_TO_WEST 1   /* Axis1=L, Direction=L, Axis2=H */
#define SOUTH_TO_NORTH 2 /* Axis1=L, Direction=H, Axis2=L */
#define WEST_TO_EAST 3   /* Axis1=L, Direction=H, Axis2=H */
#define TOP_TO_BOTTOM 4  /* Axis1=H, Direction=L, Axis2=L */
#define BOTTOM_TO_TOP 5  /* Axis1=H, Direction=L, Axis2=H */

// Constants
#define NUMBER_OF_ROUNDS 32
#define NUMBER_OF_ZEROCROSSINGS 16
#define DISTANCE 0.2  // Distance between transducers in meters

// Variables to handle timing and measurement
volatile uint8_t pulse_count;
volatile uint8_t axis_direction;
volatile uint8_t round_count;
volatile uint8_t measure_set;
volatile uint8_t calc_set;
volatile uint8_t done_flag;
volatile uint32_t envelope[2][6];  // Stores envelope times for 6 directions
volatile uint8_t zerocrossing_count;
volatile uint32_t zerocrossing[2][6][NUMBER_OF_ROUNDS];  // Zero-crossing times for 6 directions

// Time-of-flight variables for each direction
int32_t envelope_tof_ns[6];      // Envelope ToF for 6 directions
int32_t zerocrossing_tof_ns[6];  // Zero-crossing ToF for 6 directions

// Variables for wind speed calculations
float wind_ns_total = 0;
float wind_ew_total = 0;
float wind_tb_total = 0;
uint8_t sample_count = 0;

// PWM settings for timing (compare register values)
#define OCR1AH_PWM 0x01  // PWM setting for Output Compare Register A
#define OCR1AL_PWM 0x8F  // PWM setting for Output Compare Register A
#define OCR1BH_PWM 0x00  // PWM setting for Output Compare Register B
#define OCR1BL_PWM 0xC7  // PWM setting for Output Compare Register B
#define OCR1AH_LONG 0xC4 // Long setting for Output Compare Register A (double interval)
#define OCR1AL_LONG 0xDE // Long setting for Output Compare Register A (double interval)
#define OCR1BH_LONG 0x0F // Long setting for Output Compare Register B (double interval)
#define OCR1BL_LONG 0x9E // Long setting for Output Compare Register B (double interval)

void setup() {
  // Initialize control variables
  pulse_count = 0;
  axis_direction = 0;
  round_count = 0;
  measure_set = 0;
  calc_set = 1;
  done_flag = 0;
  sample_count = 0;
  wind_ns_total = 0;
  wind_ew_total = 0;
  wind_tb_total = 0;

  // Configure pins as outputs
  pinMode(AXIS1, OUTPUT);
  pinMode(AXIS2, OUTPUT);
  pinMode(DIRECTION, OUTPUT);
  pinMode(SIGNAL, OUTPUT);
  pinMode(MUTE, OUTPUT);
  pinMode(TMR1_COMPB_INT, OUTPUT);
  pinMode(TMR1_CAPTURE_INT, OUTPUT);
  pinMode(CALC, OUTPUT);

  // Initialize serial communication
  Serial.begin(9600);

  // Configure Timer1 for Fast PWM mode, prescaler=1
  TCCR1A = 0b00100011;
  TCCR1B = 0b11011001;
  TIMSK1 = 0b00000100;

  // Set PWM values in the output compare registers
  OCR1AH = OCR1AH_PWM;
  OCR1AL = OCR1AL_PWM;
  OCR1BH = OCR1BH_PWM;
  OCR1BL = OCR1BL_PWM;

  // Analog comparator settings
  ADCSRB = 0b00000000;
  ACSR = 0b01000100;

  // Initialize LCD display
  lcd.begin(16, 2);
  lcd.setCursor(0, 0);
  lcd.print("3D Ultrasonic");
  lcd.setCursor(0, 1);
  lcd.print("Anemometer");
}

// Timer1 Compare B interrupt service routine
ISR(TIMER1_COMPB_vect) {
  digitalWrite(TMR1_COMPB_INT, HIGH); // Signal interrupt
  ++pulse_count;

  switch (pulse_count) {
    case 15:
      TCCR1A = 0b00000011;  // Disable PWM output

      // Set longer interval
      OCR1AH = OCR1AH_LONG; 
      OCR1AL = OCR1AL_LONG;
      OCR1BH = OCR1BH_LONG;
      OCR1BL = OCR1BL_LONG;
      break;

    case 16:
      digitalWrite(MUTE, LOW);  // Unmute the amplifier for listening
      ACSR = 0b01000100;        // Analog comparator trigger
      TIFR1 = 0b00100000;       // Clear interrupt flag
      TIMSK1 = 0b00100100;      // Enable input capture interrupts
      zerocrossing_count = 0;

      // Reset PWM values
      OCR1AH = OCR1AH_PWM;      
      OCR1AL = OCR1AL_PWM;
      OCR1BH = OCR1BH_PWM;
      OCR1BL = OCR1BL_PWM;
      break;

    case 17:
      ++axis_direction;
      if (axis_direction >= 6) {
        axis_direction = 0;  // Reset direction when all have been measured
      }

      digitalWrite(MUTE, HIGH); // Mute amplifier for the next pulse burst

      // Set axis and direction for the next measurement
      digitalWrite(DIRECTION, (axis_direction & 0b010) ? HIGH : LOW);
      digitalWrite(AXIS2, (axis_direction & 0b001) ? HIGH : LOW);
      digitalWrite(AXIS1, (axis_direction & 0b100) ? HIGH : LOW);

      if (axis_direction == 0) {
        ++round_count;
        if (round_count == NUMBER_OF_ROUNDS) {
          round_count = 0;
          measure_set ^= 1;   // Toggle measurement and calculation set
          calc_set ^= 1;
          done_flag = 1;      // Measurement done

          // Reset envelope values
          for (uint8_t i = 0; i < 6; ++i) {
            envelope[measure_set][i] = 192000; // 15 pulses * (16MHz/40kHz) * 32 rounds
          }
        }
      }
      break;

    case 18:
      TCCR1A = 0b00100011; // Enable PWM output
      pulse_count = 0;     // Reset pulse count
      break;
  }
  digitalWrite(TMR1_COMPB_INT, LOW); // Clear interrupt signal
}

// Timer1 Input Capture interrupt service routine for actual measurement
ISR(TIMER1_CAPT_vect) {
  asm("sbi %0, %1 \n\t" ::"I"(_SFR_IO_ADDR(PORTC)), "I"(PORTC4));  // Set pin A4 high

  // Capture timer value when interrupt occurs
  uint16_t timer_value;
  uint8_t timer_low = ICR1L;  // Read low byte of Input Capture Register
  timer_value = ICR1H;        // Read high byte of Input Capture Register
  timer_value <<= 8;          // Shift high byte to correct position
  timer_value |= timer_low;   // Combine low and high byte to form 16-bit timer value

  // Handle Envelope Detector case (first event of measurement)
  if (zerocrossing_count == 0) {
    envelope[measure_set][axis_direction] += timer_value;  // Add timer value to envelope
    zerocrossing[measure_set][axis_direction][round_count] = 72000; // Initialize zero-crossing value (16MHz/40kHz * 15 pulses * 16 zero crossings - 24000 ticks to align crossings)
    ACSR = 0b01000000;  // Set analog comparator to use zero-crossing detector
    TCCR1B = 0b11011001;  // Set rising edge as input capture trigger
  } else {
    zerocrossing[measure_set][axis_direction][round_count] += timer_value;  // Add timer value to zero-crossing array
    TCCR1B ^= 0b01000000;  // Toggle edge for next capture

    if (zerocrossing_count == NUMBER_OF_ZEROCROSSINGS) {
      TIMSK1 = 0b00000100;  // Disable input capture interrupts
    }
  }

  ++zerocrossing_count;
  asm volatile("cbi %0, %1 \n\t" ::"I"(_SFR_IO_ADDR(PORTC)), "I"(PORTC4));  // Set pin A4 low
}

// Function to calculate temperature from analog sensor
float temperature() {
  float temp = (float)analogRead(TEMPERATURE_SENSOR);
  return temp / 0.057;  // Convert sensor reading to degrees Celsius
}

// Function to calculate wind speed using time difference
double windspeed(int16_t timediff) {
  if (timediff == 0) {
    return 0.0;  // No wind if timediff is zero
  }
  float temperature = temperature();  // Get the current temperature in Celsius
  double sos = 331.3 * sqrt(1 + (temperature / 273.15));  // Speed of sound formula
  double a = (double)timediff * -0.000000001; // Time difference in nanoseconds
  double b = 2 * DISTANCE;
  double c = a * pow(sos, 2);
  double discriminant = (b * b) - (4 * a * c);
  double wind = (-b + sqrt(discriminant)) / (2 * a);  // Solve quadratic equation
  return wind;
}

void loop() {
  // Process results when measurement is complete (done_flag is set)
  if (done_flag) {
    digitalWrite(CALC, HIGH);  // Signal calculation in progress

    // Convert time-of-flight values to nanoseconds
    for (uint8_t dir = 0; dir < 6; ++dir) {
      envelope_tof_ns[dir] = envelope[calc_set][dir] * 125 >> 6;  // ((env[][]*1/16MHz)/32 rounds)
      zerocrossing_tof_ns[dir] = 0;
      uint32_t reference = envelope[calc_set][dir] >> 1;
      for (uint8_t i = 0; i < NUMBER_OF_ROUNDS; ++i) {
        // For all 32 rounds, adjust zero-crossing time to ensure the first zero crossing starts at envelope
        while (zerocrossing[calc_set][dir][i] > reference)
          zerocrossing[calc_set][dir][i] -= 6400;
        zerocrossing_tof_ns[dir] += zerocrossing[calc_set][dir][i];
      }
      zerocrossing_tof_ns[dir] *= 125 >> 10;  //((zcd[][]*1/16MHz)/(32 rounds * 16 zero crossings)
    }

    // Calculate wind speeds for the three axes
    int32_t diff_ns = zerocrossing_tof_ns[NORTH_TO_SOUTH] - zerocrossing_tof_ns[SOUTH_TO_NORTH];
 
    while (diff_ns < -12500)
      diff_ns += 25000;
    while (diff_ns > 12500)
      diff_ns -= 25000;

    float wind_ns = windspeed(diff_ns);

    int32_t diff_ew = zerocrossing_tof_ns[EAST_TO_WEST] - zerocrossing_tof_ns[WEST_TO_EAST];

    while (diff_ew < -12500)
      diff_ew += 25000;
    while (diff_ew > 12500)
      diff_ew -= 25000;
    float wind_ew = windspeed(diff_ew);

    int32_t diff_tb = zerocrossing_tof_ns[TOP_TO_BOTTOM] - zerocrossing_tof_ns[BOTTOM_TO_TOP];

    while (diff_tb < -12500)
      diff_tb += 25000;
    while (diff_tb > 12500)
      diff_tb -= 25000;
    float wind_tb = windspeed(diff_tb);

    // Accumulate wind speed measurements
    wind_ns_total += wind_ns;
    wind_ew_total += wind_ew;
    wind_tb_total += wind_tb;
    sample_count++;

    // After every 5 samples, calculate average and display results
    if (sample_count == 5) {
      float avg_wind_ns = wind_ns_total / 5;
      float avg_wind_ew = wind_ew_total / 5;
      float avg_wind_tb = wind_tb_total / 5;

      // Calculate total wind magnitude using all axes
      float magnitude = sqrt(avg_wind_ns * avg_wind_ns + avg_wind_ew * avg_wind_ew + avg_wind_tb * avg_wind_tb);

      // Calculate wind phase (horizontal direction)
      float phase = atan2(avg_wind_ns, avg_wind_ew) * (180.0 / PI);  // Convert radians to degrees
      if (phase < 0) {
        phase += 360.0;
      }
      phase = 90.0 - phase;  // Adjust phase to match wind direction convention
      if (phase < 0) {
        phase += 360.0;
      }

      // Calculate elevation angle (vertical direction)
      float horizontal_magnitude = sqrt(avg_wind_ns * avg_wind_ns + avg_wind_ew * avg_wind_ew);
      float elevation = atan2(avg_wind_tb, horizontal_magnitude) * (180.0 / PI);  // Elevation in degrees

      // Output results to serial for plotting
      Serial.print("NS:");
      Serial.print(avg_wind_ns, 2);
      Serial.print(",EW:");
      Serial.print(avg_wind_ew, 2);
      Serial.print(",TB:");
      Serial.print(avg_wind_tb, 2);
      Serial.print(",Mag:");
      Serial.print(magnitude, 2);
      Serial.print(",Phase:");
      Serial.print(phase, 2);
      Serial.print(",Elevation:");
      Serial.println(elevation, 2);

      // Reset totals and sample count
      wind_ns_total = 0;
      wind_ew_total = 0;
      wind_tb_total = 0;
      sample_count = 0;
    }

    done_flag = 0;  // Reset done flag
    digitalWrite(CALC, LOW);  // End calculation signal
  }
}
